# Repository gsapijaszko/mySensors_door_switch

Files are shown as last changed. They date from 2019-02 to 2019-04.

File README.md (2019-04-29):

# mySensors_door_switch
a simple door/window sensor with Li-Ion battery circuit, nRF24 radio, mySensors network

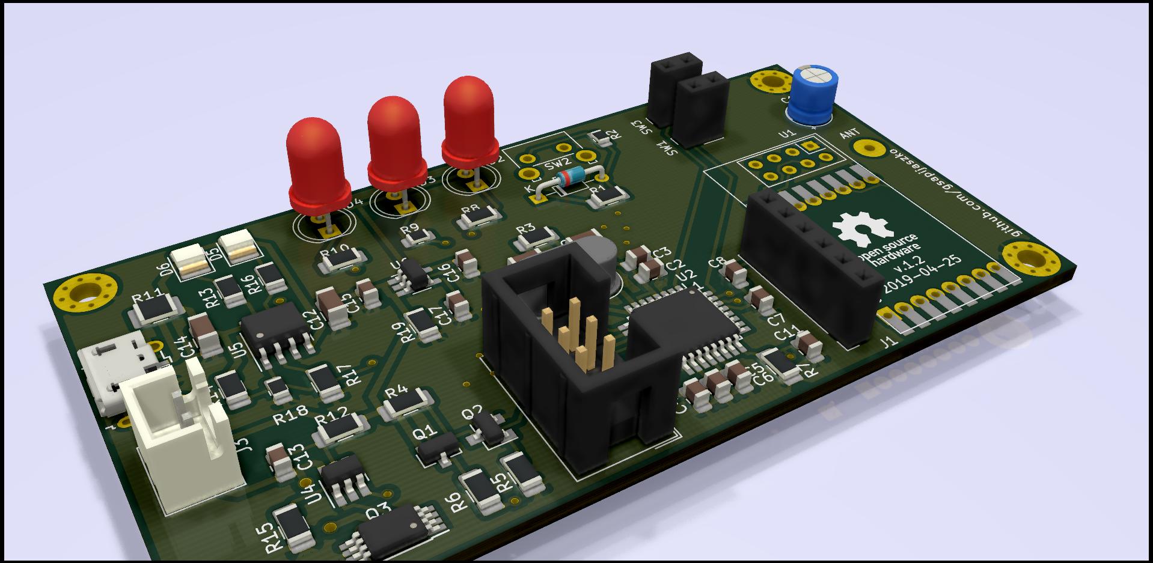
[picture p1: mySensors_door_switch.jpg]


work in progress, do not expect to much ;)

## Changes
### ver. 1.1
* corrected battery charging schema and pcb
* battery protection changed from DW01 to FS312 
### ver. 1.2, 29.04.2019
* change of ADC pin
* added second reed switch 
* PCB layout correction

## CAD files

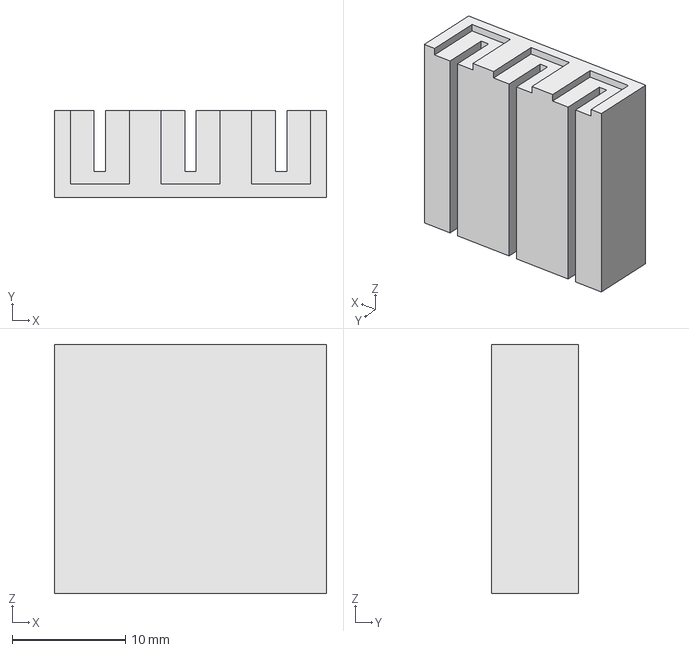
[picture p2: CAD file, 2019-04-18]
case/LED_support.FCStd
24.0 x 7.70 x 22.0 mm

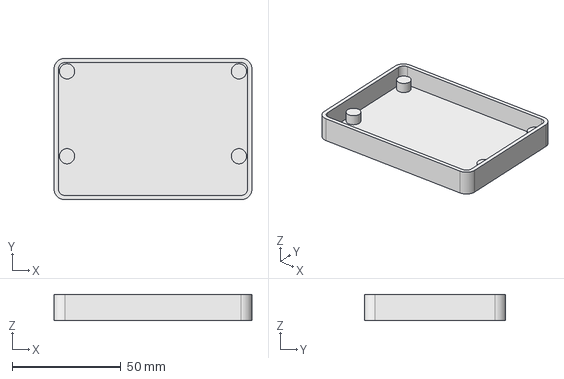
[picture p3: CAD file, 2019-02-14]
case/bottom_part.FCStd
91.0 x 65.0 x 12.0 mm

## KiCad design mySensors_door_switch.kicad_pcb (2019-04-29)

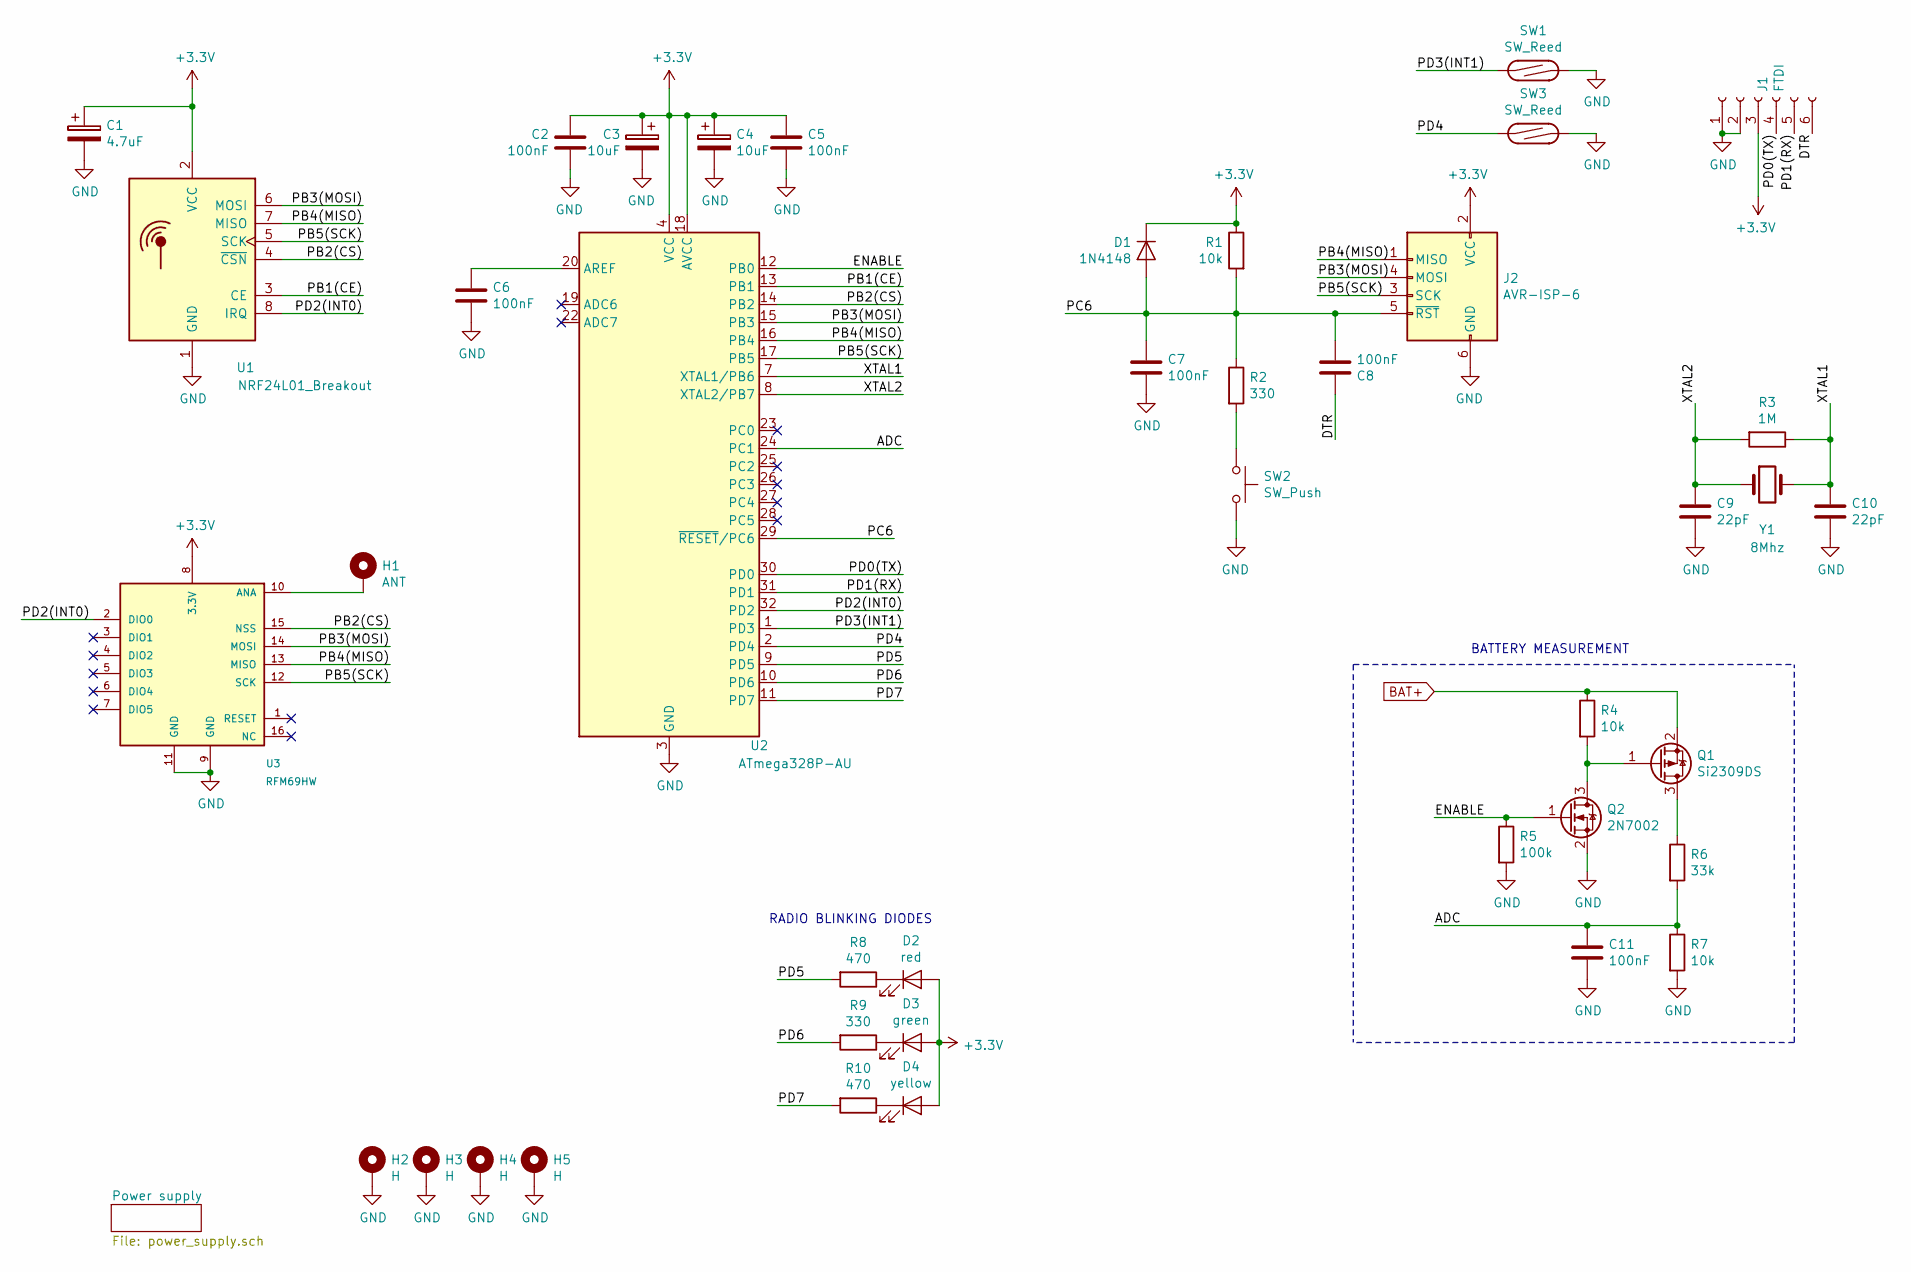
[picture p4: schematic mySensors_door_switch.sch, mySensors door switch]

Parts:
C1: 4.7uF; CP_Radial_D5.0mm_P2.50mm
C2, C5, C6, C7, C8, C11: 100nF; C_0805_2012Metric_Pad1.15x1.40mm_HandSolder
C3, C4: 10uF; C_0805_2012Metric_Pad1.15x1.40mm_HandSolder
C9, C10: 22pF; C_1206_3216Metric_Pad1.42x1.75mm_HandSolder
D1: 1N4148; D_DO-34_SOD68_P7.62mm_Horizontal
D2: red; LED_D5.0mm
D3: green; LED_D5.0mm
D4: yellow; LED_D5.0mm
H1: ANT; SolderWirePad_1x01_Drill1.2mm
H2, H3, H4, H5: H; MountingHole_2.7mm_M2.5_Pad_Via
J1: FTDI; PinSocket_1x06_P2.54mm_Vertical
J2: AVR-ISP-6; IDC-Header_2x03_P2.54mm_Vertical
Q1: Si2309DS; SOT-23
Q2: 2N7002; SuperSOT-3
R1, R4, R7: 10k; R_1206_3216Metric_Pad1.42x1.75mm_HandSolder
R2, R9: 330; R_0805_2012Metric_Pad1.15x1.40mm_HandSolder
R3: 1M; R_1206_3216Metric_Pad1.42x1.75mm_HandSolder
R5: 100k; R_1206_3216Metric_Pad1.42x1.75mm_HandSolder
R6: 33k; R_1206_3216Metric_Pad1.42x1.75mm_HandSolder
R8, R10: 470; R_1206_3216Metric_Pad1.42x1.75mm_HandSolder
SW1, SW3: SW_Reed; PinSocket_1x02_P2.54mm_Vertical
SW2: SW_Push; SW_Tactile_SKHH_Angled
U1: NRF24L01_Breakout; nRF24L01_Breakout
U2: ATmega328P-AU; TQFP-32_7x7mm_P0.8mm
U3: RFM69HW; RFM69HW_SMD_ThroughHole_Handsoldering
Y1: 8Mhz; Crystal_HC49-4H_Vertical

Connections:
+3V3: C1.1, C2.1, C3.1, C4.1, C5.1, D1.1 (K), D2.2 (A), D3.2 (A), D4.2 (A), J1.3, J2.2 (VCC), R1.1, U1.2 (VCC), U2.4 (VCC), U2.6 (VCC), U2.18 (AVCC), U3.8 (3.3V); also elsewhere on the board
/ADC: C11.1, R6.2, R7.1, U2.24 (PC1)
/DTR: C8.1, J1.6
/ENABLE: Q2.1 (G), R5.1, U2.12 (PB0)
/PB1(CE): U1.3 (CE), U2.13 (PB1)
/PB2(CS): U1.4 (~CSN), U2.14 (PB2), U3.15 (NSS)
/PB3(MOSI): J2.4 (MOSI), U1.6 (MOSI), U2.15 (PB3), U3.14 (MOSI)
/PB4(MISO): J2.1 (MISO), U1.7 (MISO), U2.16 (PB4), U3.13 (MISO)
/PB5(SCK): J2.3 (SCK), U1.5 (SCK), U2.17 (PB5), U3.12 (SCK)
/PC6: C7.1, C8.2, D1.2 (A), J2.5 (~RST), R1.2, R2.1, U2.29 (~RESET~/PC6)
/PD0(TX): J1.4, U2.30 (PD0)
/PD1(RX): J1.5, U2.31 (PD1)
/PD2(INT0): U1.8 (IRQ), U2.32 (PD2), U3.2 (DIO0)
/PD3(INT1): SW1.1, U2.1 (PD3)
/PD4: SW3.1, U2.2 (PD4)
/PD5: R8.2, U2.9 (PD5)
/PD6: R9.2, U2.10 (PD6)
/PD7: R10.2, U2.11 (PD7)
/XTAL1: C10.1, R3.1, U2.7 (XTAL1/PB6), Y1.2
/XTAL2: C9.1, R3.2, U2.8 (XTAL2/PB7), Y1.1
BAT+: Q1.2 (S), R4.1; also elsewhere on the board
GND: C1.2, C2.2, C3.2, C4.2, C5.2, C6.2, C7.2, C9.2, C10.2, C11.2, H2.1, H3.1, H4.1, H5.1, J1.1, J1.2, J2.6 (GND), Q2.2 (S), R5.2, R7.2, SW1.2, SW2.2, SW3.2, U1.1 (GND), U2.3 (GND), U2.5 (GND), U2.21 (GND), U3.9 (GND), U3.11 (GND); also elsewhere on the board
unnamed: C6.1, U2.20 (AREF)
unnamed: D2.1 (K), R8.1
unnamed: D3.1 (K), R9.1
unnamed: D4.1 (K), R10.1
unnamed: H1.1, U3.10 (ANA)
unnamed: Q1.1 (G), Q2.3 (D), R4.2
unnamed: Q1.3 (D), R6.1
unnamed: R2.2, SW2.1

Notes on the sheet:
RADIO BLINKING DIODES
BATTERY MEASUREMENT

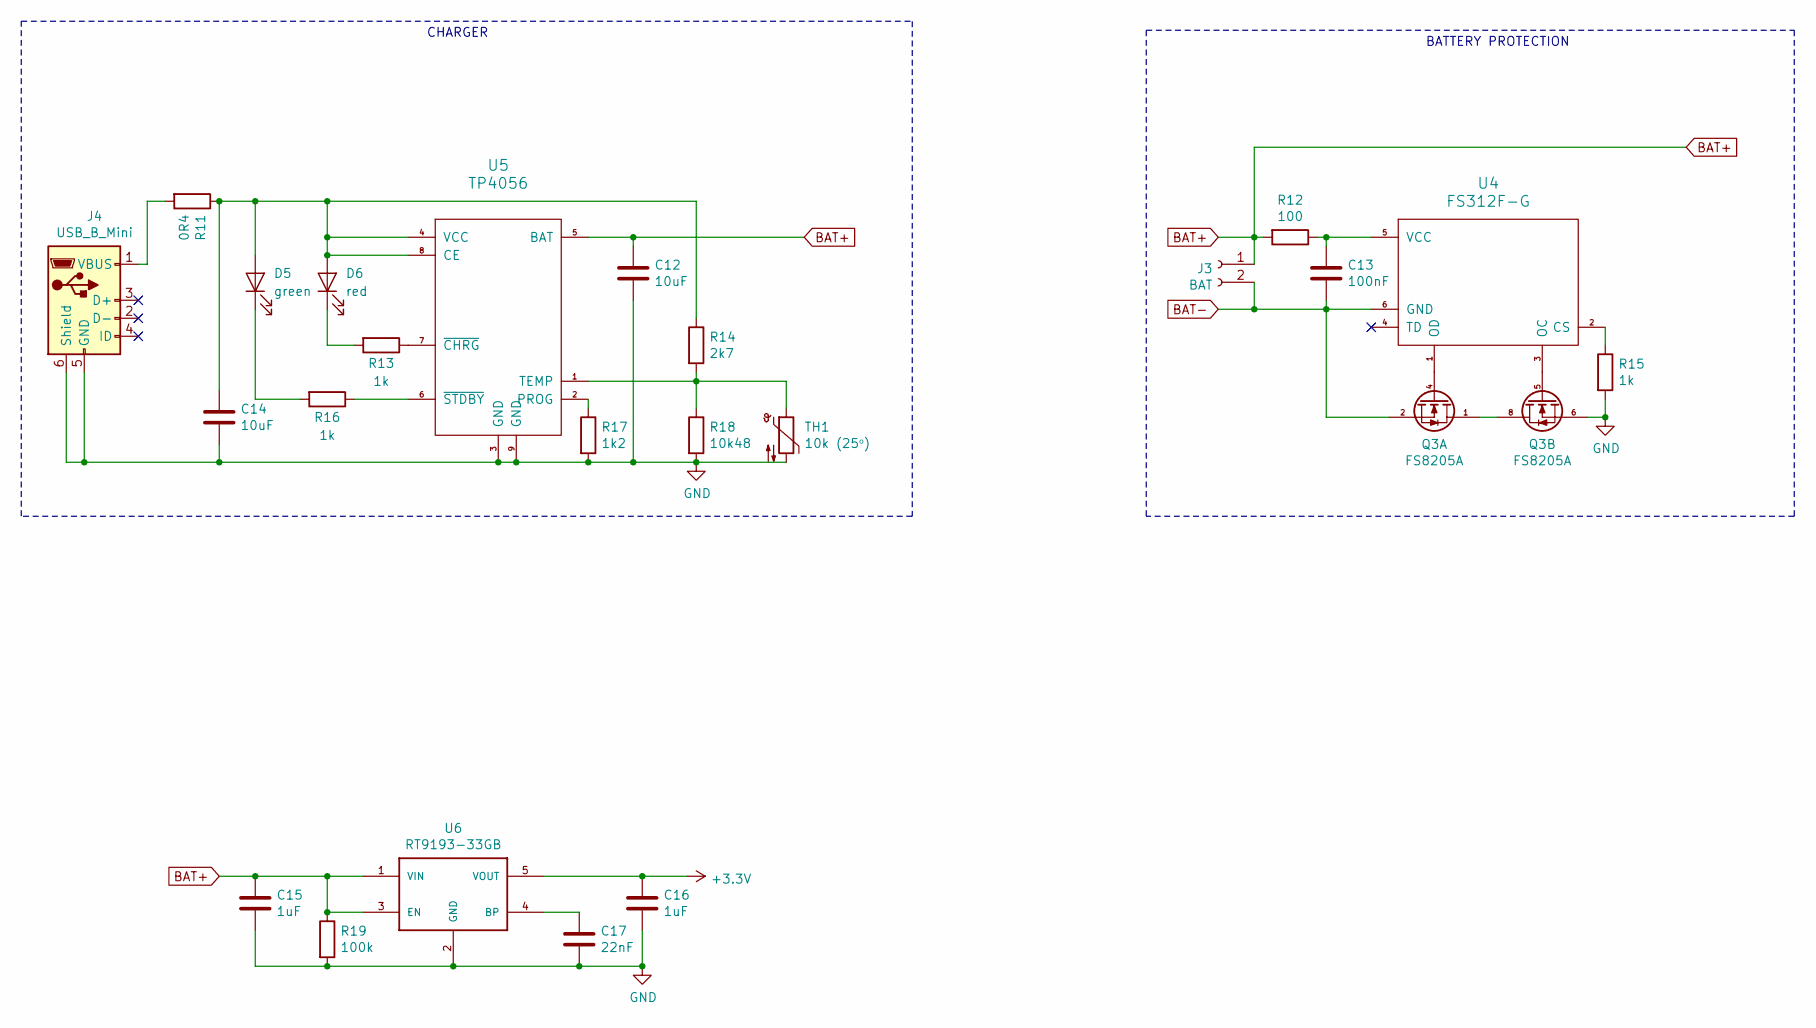
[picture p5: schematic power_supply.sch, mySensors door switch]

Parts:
C12, C14: 10uF; C_1206_3216Metric_Pad1.42x1.75mm_HandSolder
C13: 100nF; C_0805_2012Metric_Pad1.15x1.40mm_HandSolder
C15, C16: 1uF; C_0805_2012Metric_Pad1.15x1.40mm_HandSolder
C17: 22nF; C_0805_2012Metric_Pad1.15x1.40mm_HandSolder
D5: green; LED_1210_3225Metric_Pad1.42x2.65mm_HandSolder
D6: red; LED_1210_3225Metric_Pad1.42x2.65mm_HandSolder
J3: BAT; JST_XH_S02B-XH-A_1x02_P2.50mm_Horizontal
J4: USB_B_Mini; USB_Micro-B_Wuerth_629105150521
Q3: FS8205A; TSSOP-8_4.4x3mm_P0.65mm
R11: 0R4; R_1210_3225Metric_Pad1.42x2.65mm_HandSolder
R12: 100; R_1206_3216Metric_Pad1.42x1.75mm_HandSolder
R13, R15, R16: 1k; R_1206_3216Metric_Pad1.42x1.75mm_HandSolder
R14: 2k7; R_1206_3216Metric_Pad1.42x1.75mm_HandSolder
R17: 1k2; R_1206_3216Metric_Pad1.42x1.75mm_HandSolder
R18: 10k48; R_0805_2012Metric_Pad1.15x1.40mm_HandSolder
R19: 100k; R_1206_3216Metric_Pad1.42x1.75mm_HandSolder
TH1: 10k (25ᵒ); R_1218_3246Metric_Pad1.22x4.75mm_HandSolder
U4: FS312F-G; SOT-23-6_Handsoldering
U5: TP4056; HSOP-8-1EP_3.9x4.9mm_P1.27mm_EP2.41x3.1mm_ThermalVias
U6: RT9193-33GB; SOT-23-5_HandSoldering

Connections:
+3V3: C16.1, U6.5 (VOUT); also elsewhere on the board
BAT+: C12.1, C15.1, J3.1, R12.2, R19.1, U5.5 (BAT), U6.1 (VIN), U6.3 (EN); also elsewhere on the board
BAT-: C13.2, J3.2, Q3.2 (S1), U4.6 (GND)
GND: C12.2, C14.2, C15.2, C16.2, C17.2, J4.5 (GND), J4.6 (Shield), Q3.6 (S1), R15.2, R17.2, R18.2, R19.2, TH1.2, U5.3 (GND), U5.9 (GND), U6.2 (GND); also elsewhere on the board
unnamed: C13.1, R12.1, U4.5 (VCC)
unnamed: C14.1, D5.2 (A), D6.2 (A), R11.1, R14.1, U5.4 (VCC), U5.8 (CE)
unnamed: C17.1, U6.4 (BP)
unnamed: D5.1 (K), R16.2
unnamed: D6.1 (K), R13.2
unnamed: J4.1 (VBUS), R11.2
unnamed: Q3.1 (D), Q3.8 (D)
unnamed: Q3.4 (G2), U4.1 (OD)
unnamed: Q3.5 (G2), U4.3 (OC)
unnamed: R13.1, U5.7 (~CHRG)
unnamed: R14.2, R18.1, TH1.1, U5.1 (TEMP)
unnamed: R15.1, U4.2 (CS)
unnamed: R16.1, U5.6 (~STDBY)
unnamed: R17.1, U5.2 (PROG)

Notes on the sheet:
CHARGER
BATTERY PROTECTION

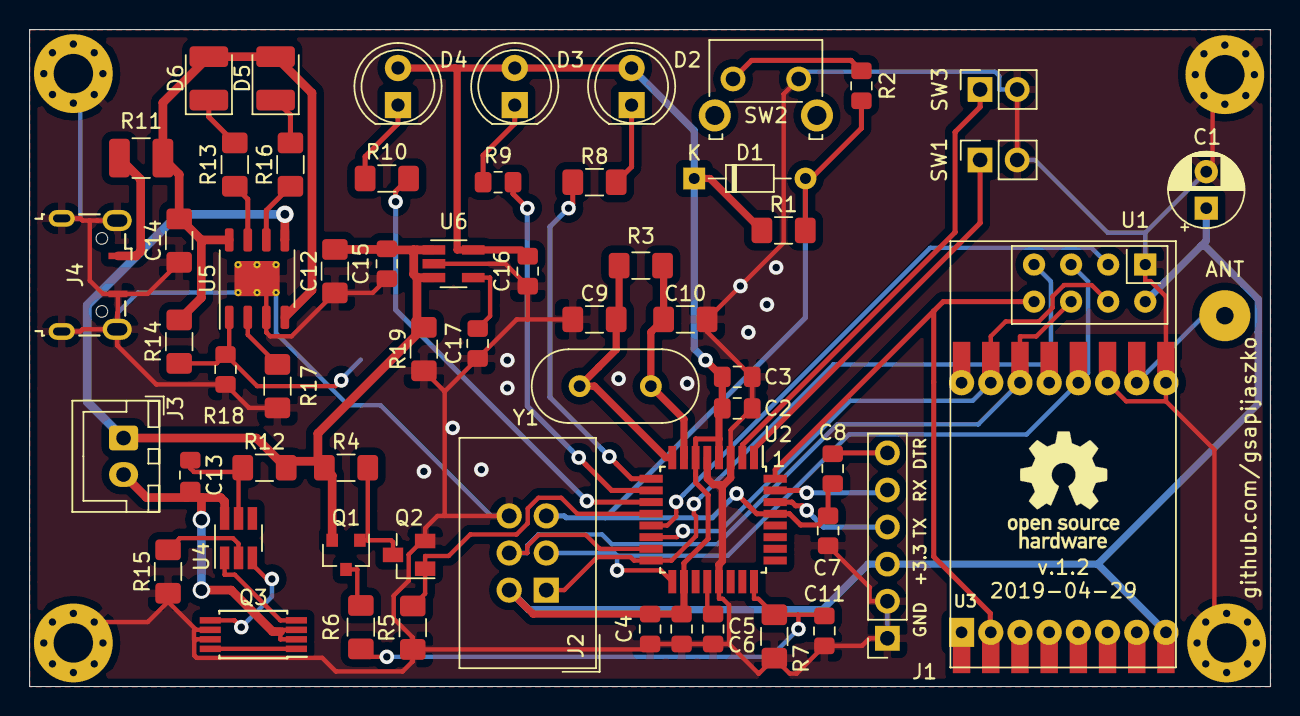
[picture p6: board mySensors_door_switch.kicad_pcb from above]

Board: 2 copper layers, 85.0 x 45.0 mm, 65 parts (1 on the bottom side), 45 nets.

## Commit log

2019-01-16 Update LICENSE, README.md, and 16 more files...
    [mySensors_door_switch.dsn, mySensors_door_switch.kicad_pcb, mySensors_door_switch.ods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]
2019-01-18 Update mySensors_door_switch.kicad_pcb and mySensors_door_switch.kicad_pcb-bak
    [mySensors_door_switch.kicad_pcb]
2019-01-22 Update fp-info-cache, mySensors_door_switch.kicad_pcb, and mySensors_door_switch.kicad_pcb-bak
    [mySensors_door_switch.kicad_pcb]
2019-01-23 Update fp-info-cache, mySensors_door_switch-cache.lib, and 11 more files...
    [mySensors_door_switch.dsn, mySensors_door_switch.kicad_pcb, mySensors_door_switch.sch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]
2019-01-23 Update fp-info-cache, mySensors_door_switch-cache.lib, and 7 more files...
    [mySensors_door_switch.kicad_pcb, mySensors_door_switch.sch, power_supply.sch]
2019-01-24 Update fp-info-cache, mySensors_door_switch-B_Cu.gbr, and 21 more files...
    [mySensors_door_switch-B_Cu.gbr, mySensors_door_switch-B_Mask.gbr, mySensors_door_switch-B_Paste.gbr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]
2019-01-24 Update fp-info-cache, mySensors_door_switch-cache.lib, and 13 more files...
    [mySensors_door_switch.dsn, mySensors_door_switch.kicad_pcb, mySensors_door_switch.sch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]
2019-01-24 Update mySensors_door_switch.jpg, mySensors_door_switch.kicad_pcb, and 2 more files...
    [mySensors_door_switch.kicad_pcb]
2019-01-26 Update LICENSE, ibom.html, and 24 more files...
    [mySensors_door_switch-B.Cu.gbr, mySensors_door_switch-B.Mask.gbr, mySensors_door_switch-B.Paste.gbr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]
2019-01-28 Update fp-info-cache, mySensors_door_switch.dsn, and 4 more files...
    [mySensors_door_switch.dsn, mySensors_door_switch.kicad_pcb]
2019-01-28 Update mySensors_door_switch-B_Cu.gbr, mySensors_door_switch-B_Mask.gbr, and 9 more files...
    [mySensors_door_switch-B_Cu.gbr, mySensors_door_switch-B_Mask.gbr, mySensors_door_switch-B_Paste.gbr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]
2019-01-28 Update fp-info-cache, mySensors_door_switch-B.Cu.gbr, and 19 more files...
    [mySensors_door_switch-B.Cu.gbr, mySensors_door_switch-B.Mask.gbr, mySensors_door_switch-B.Paste.gbr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]
2019-02-11 Update fp-info-cache, mySensors_door_switch.jpg, and 2 more files...
    [mySensors_door_switch.kicad_pcb]
2019-02-11 Update ibom.html, mySensors_door_switch.kicad_pcb, and mySensors_door_switch.kicad_pcb-bak
    [mySensors_door_switch.kicad_pcb]
2019-02-14 Update bottom_part.FCStd, bottom_part.FCStd1, and 2 more files...
    [bottom_part.FCStd, mySensors_door_switch.kicad_pcb]
2019-03-08 Battery charging circuit update
    [power_supply.sch]
2019-03-09 Update fp-info-cache, mySensors_door_switch-cache.lib, and 12 more files...
    [mySensors_door_switch.dsn, mySensors_door_switch.kicad_pcb, mySensors_door_switch.sch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]
2019-03-12 Update README.md, mySensors_door_switch-cache.lib, and 7 more files...
    [mySensors_door_switch.kicad_pcb, mySensors_door_switch.sch, power_supply.sch]
2019-03-13 Update mySensors_door_switch.jpg, mySensors_door_switch.kicad_pcb, and mySensors_door_switch.kicad_pcb-bak
    [mySensors_door_switch.kicad_pcb]
2019-03-17 Revert "Revert "Update mySensors_door_switch.jpg, mySensors_door_switch.kicad_pcb, and mySensors_door_switch.kicad_pcb-bak""
    This reverts commit b69a79a09ae4543226fbccfdd42f2f386e584dfe.
2019-03-25 Update fp-info-cache, mySensors_door_switch-cache.lib, and 4 more files...
    [mySensors_door_switch.sch, power_supply.sch]
2019-03-28 Update ibom.html, fp-info-cache, and 4 more files...
    [mySensors_door_switch.kicad_pcb, power_supply.sch]
2019-03-28 v.1.1, gerbers sent to PCB factory
    [mySensors_door_switch-B_Cu.gbr, mySensors_door_switch-B_Mask.gbr, mySensors_door_switch-B_Paste.gbr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]
2019-03-30 Update export.ods, mySensors_door_switch.csv, and 2 more files...
    [export.ods, mySensors_door_switch.csv, mySensors_door_switch.ods]
2019-04-18 v.1.2, small PCB changes
    [LED_support.FCStd, export.ods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]
2019-04-20 Update fp-info-cache, mySensors_door_switch-B_Cu.gbr, and 17 more files...
    [mySensors_door_switch-B_Cu.gbr, mySensors_door_switch-B_Mask.gbr, mySensors_door_switch-B_Paste.gbr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]
2019-04-20 Update fp-info-cache, mySensors_door_switch-B_Cu.gbr, and 19 more files...
    [mySensors_door_switch-B_Cu.gbr, mySensors_door_switch-B_Mask.gbr, mySensors_door_switch-B_Paste.gbr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]
2019-04-24 Update mySensors_door_switch.kicad_pcb, mySensors_door_switch.kicad_pcb-bak, and mySensors_door_switch.pro
    [mySensors_door_switch.kicad_pcb]
2019-04-24 Revert "Update mySensors_door_switch.kicad_pcb, mySensors_door_switch.kicad_pcb-bak, and mySensors_door_switch.pro"
    This reverts commit cb215671e944ab6fd4212124ce306d0e18611652.
    Conflicts:
    mySensors_door_switch.kicad_pcb
    [mySensors_door_switch.kicad_pcb]
2019-04-26 Update fp-info-cache, mySensors_door_switch.bak, and 5 more files...
    [mySensors_door_switch.kicad_pcb, mySensors_door_switch.sch]
2019-04-29 Update fp-info-cache, gerbers.zip, and 26 more files...
    [combined.GKO, combined.drl, combined.gbl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]
2019-04-29 v. 1.2 withe gerbers ready to manufacture
    [combined.GKO, combined.drl, combined.gbl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]
